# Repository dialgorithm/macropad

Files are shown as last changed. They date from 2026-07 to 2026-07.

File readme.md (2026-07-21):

# macropad

xiao esp32s3 based 10 key custom wireless macropad with a display to show the current layer and controls.

There are 10 keys, 1 layer switch button, 1 rotary encoder, and a slide switch for turning on and off.

## Schematics + PCB

Designed using KiCad.

| Schematic | PCB Layout | 3D PCB |
| --- | --- | --- |
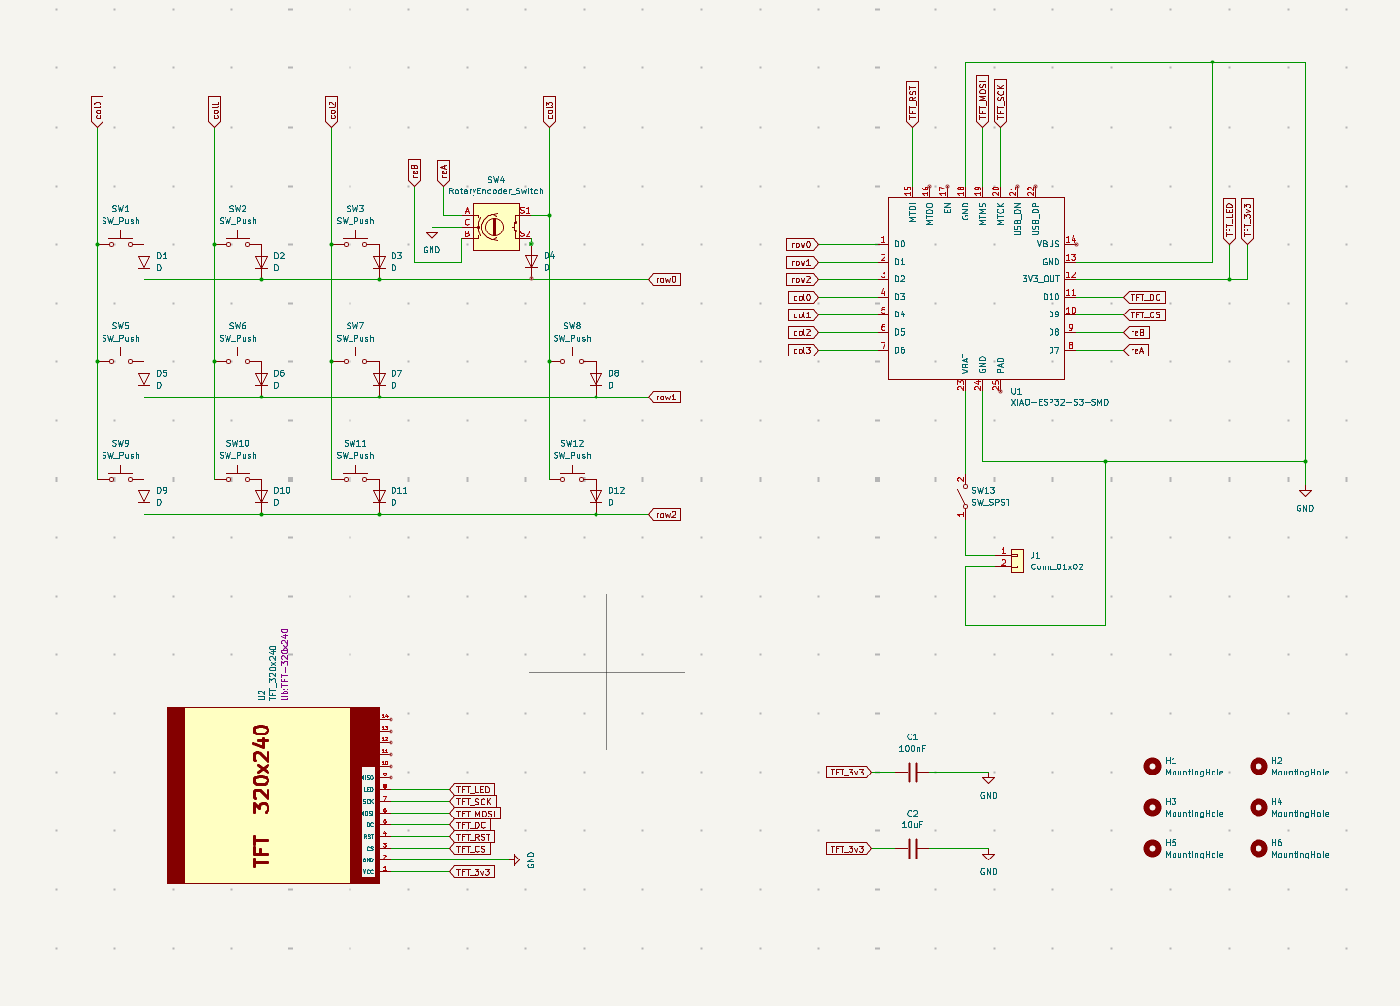
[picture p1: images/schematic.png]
schematic
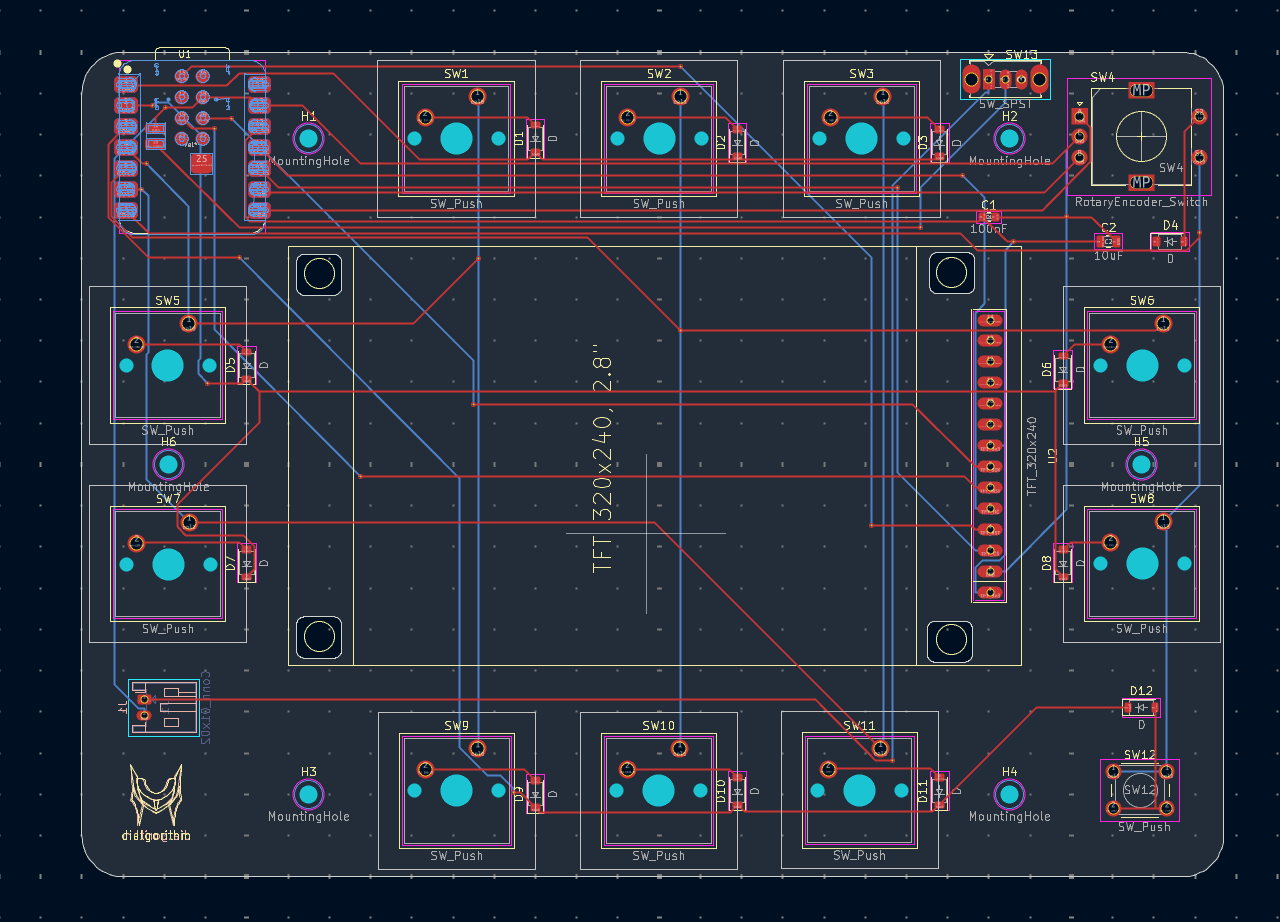
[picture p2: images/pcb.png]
pcb
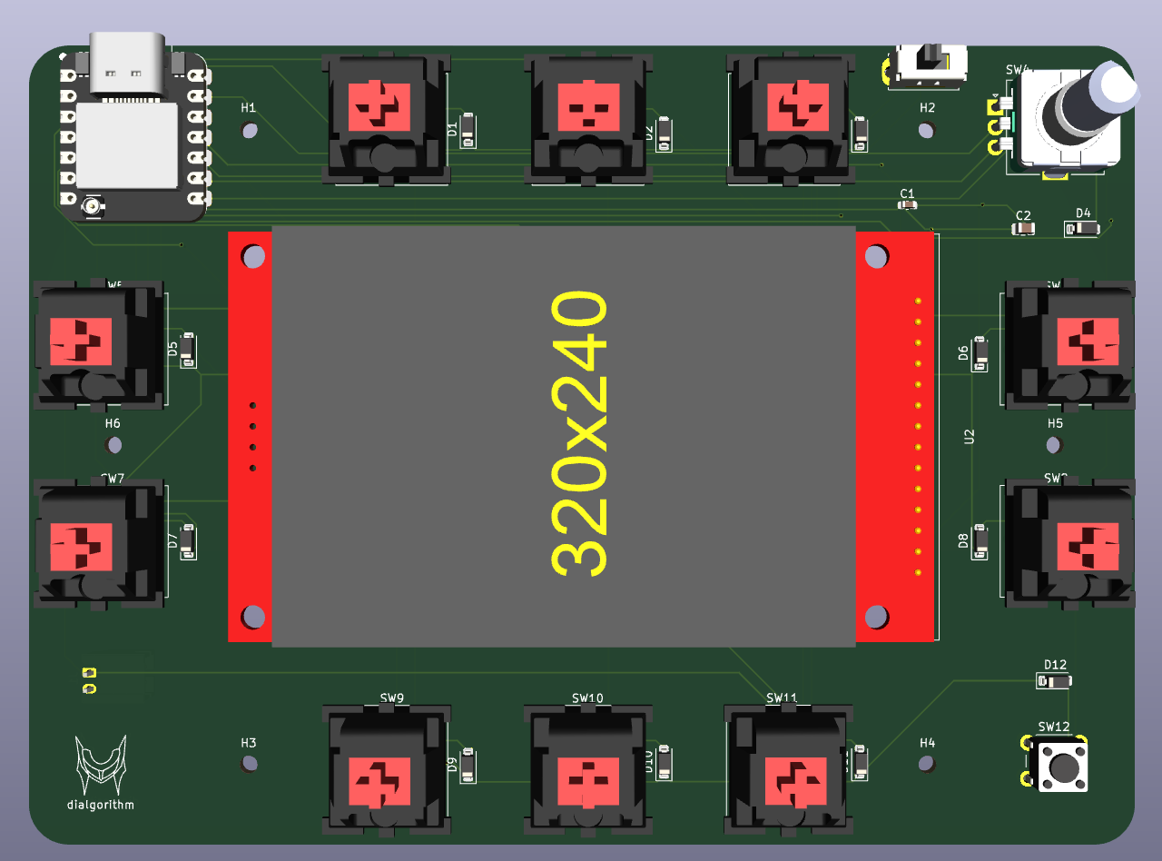
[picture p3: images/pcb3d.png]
pcb3d
|  |  |  |

## CAD

I am using cnc'd acrylic transparent sheets to keep a minimal and clean look.

| Top View | Side View | Bottom View |
| --- | --- | --- |
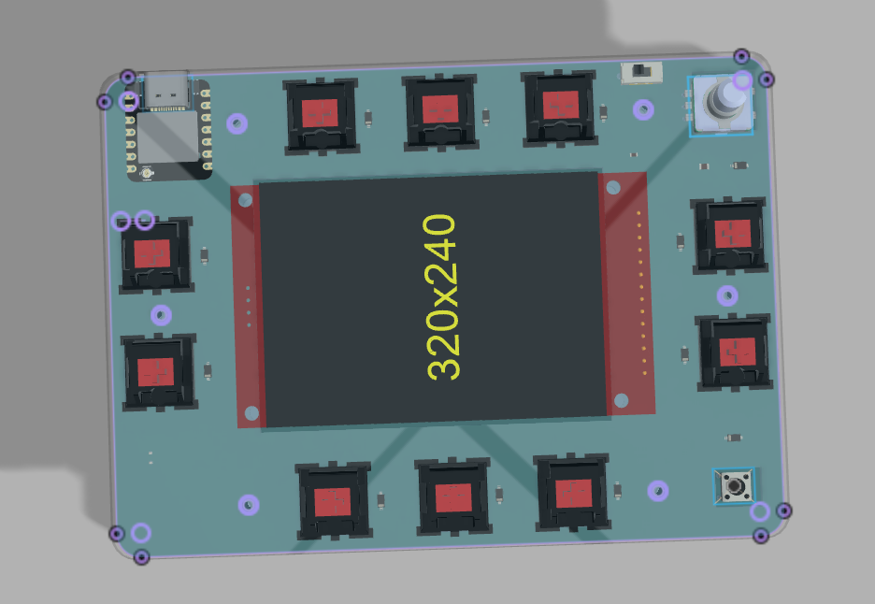
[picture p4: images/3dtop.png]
3dtop
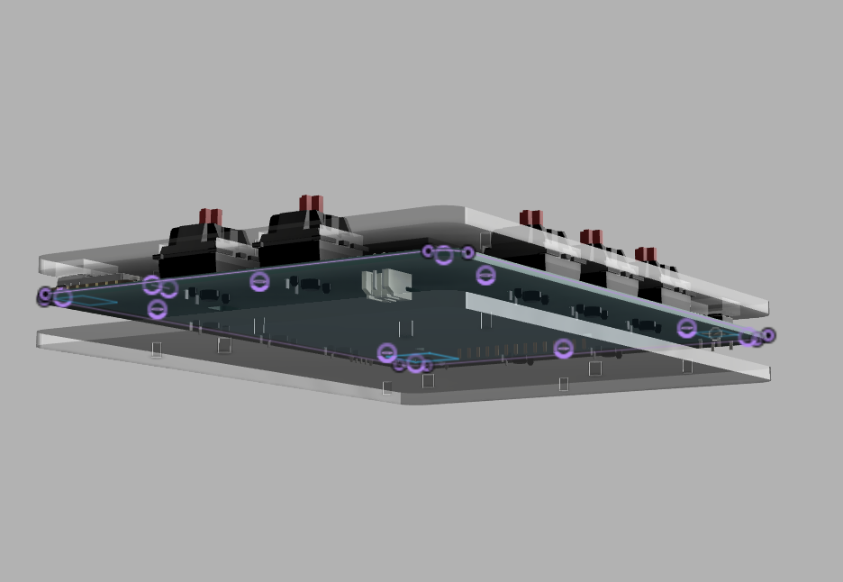
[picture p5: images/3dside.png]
3dside
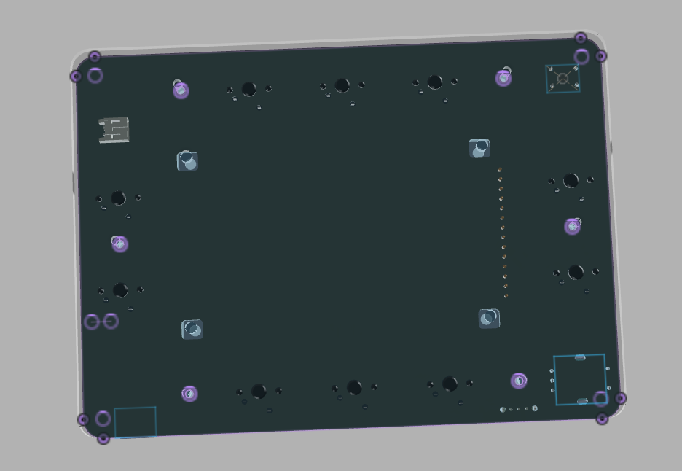
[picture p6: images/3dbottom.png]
3dbottom
|  |  |  |

## BOM

you can find the detailed bill of materials [here](bom.csv)

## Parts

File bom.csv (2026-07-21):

Item | Quantity | Cost | Source
Bottom Plate CNC | 1 | $3 | https://robu.in/product/online-laser-cutting-service/
Switch Plate CNC | 1 | $3 | https://robu.in/product/online-laser-cutting-service/
PCB | 1 | $28.5 | https://robu.in/product/online-pcb-manufacturing-service/ (JLCPCB costs $20 and with customs it would cost me $40)
XIAO ESP32-S3 | 1 | $9.5 | https://robocraze.com/products/seeed-studio-xiao-esp32-s3-development-board-supports-wi-fi-bluetooth-5-0
Switches | 10 | $5 | https://stackskb.com/store/hmx-xinhai-pack-of-10/
Push Button | 1 | $2 | https://www.amazon.in/Square-tactile-button-switch-White/dp/B0FJGXRXHX?th=1
Rotary Encoder | 1 | $1 | https://robu.in/product/hongyan-ec11h-7ce15p1zd15f7-rotary-encoder-with-push-button-switch-vertical-plug-in-5-pin-360-degree/
Encoder Knob | 1 | $0.3 | https://robu.in/product/potentiometer-knob-rotary-switch-cap-black-color-pack-of-5-pcs/
100nF 0603 Capacitor | 1 | $1.2 | https://www.amazon.in/0-1uF-100nF-Capacitor-0603-pack/dp/B0DK95ZBFM
10uF 0805 Capacitor | 1 | $3.2 | https://www.amazon.in/RajRetaiil-10uF-10000nF-Capacitor-Package/dp/B0GPW3R3TK
1N4148W Diode | 13 | $0.5 | https://robu.in/product/1n4148w-semtech-75v-independent-type-1v50ma-4ns-150ma-sod-123-switching-diodes-rohs/
Right Angle JST 2 pin | 1 | $1.2 | https://www.amazon.in/Right-Angle-Connector-2-5mm-Pitch/dp/B0CLY3CM63
Right Angle SPDT Switch | 1 | $1.2 | https://www.amazon.in/Mini-Slide-Switch-Right-Angle/dp/B0B434R6QF
Keycaps | 10 | $6.5 | https://www.amazon.in/CALANDISTM-Replacement-Switches-Keyboards-Pointers/dp/B0F14119N8?s=electronics
240x320 TFT Display | 1 | $7 | https://robu.in/product/2-4-inch-spi-interface-240x320-touch-screen-tft-display-module/
M2 6mm standoff | 6 | $2.3 | https://stackskb.com/store/m2-spacer-standoff-6mm-brass-nickel/
M2 5mm standoff | 6 | $2.3 | https://stackskb.com/store/m2-spacer-standoff-5mm-brass-nickel/
M2 10mm screws | 6 | $4 | https://www.amazon.in/BMOSESE%C2%AE-10MM-Length-Phillips-Screws/dp/B0FHHTPXD1
M2 8mm screws | 6 | $0.5 | https://stackskb.com/store/m2-screw-8mm-stainless-steel/
Rubber Feet | 6 | $4 | https://www.amazon.in/Pro3D-Vibration-Rubber-Damper-Balls/dp/B0CV9MFVJQ
Battery | 1 | $4 | https://www.amazon.in/KP-Original-902232-Rechargeable-Battery-Connector/dp/B0CY8GGW1B
Total | - | ~$95 | -

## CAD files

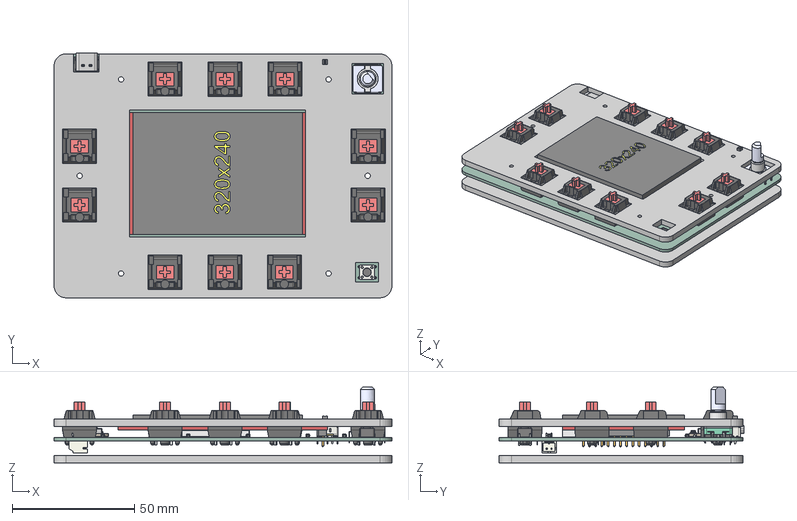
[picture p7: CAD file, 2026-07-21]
CAD/assembly.step
138.5 x 100.3 x 31.1 mm
D_SOD-123_1 x 12
C_0805_2012Metric_1
C_0603_1608Metric_1
SW_Slide_SPDT_Straight_CK_OS102011MS2Q_1
BOSS-EXTRUDE14_8_
BOSS-EXTRUDE7_4_
BOSS-EXTRUDE7_3_
BOSS-EXTRUDE14_4_
BOSS-EXTRUDE14_2_
BOSS-EXTRUDE14_11_
BOSS-EXTRUDE7_7_
BOSS-EXTRUDE14_9_
BOSS-EXTRUDE14_3_
BOSS-EXTRUDE14_7_
MIRROR2
BOSS-EXTRUDE14_5_
BOSS-EXTRUDE14_12_
BOSS-EXTRUDE7_8_
BOSS-EXTRUDE7_1_
BOSS-EXTRUDE14_10_
BOSS-EXTRUDE7_9_
BOSS-EXTRUDE14_6_
BOSS-EXTRUDE14_1_
BOSS-EXTRUDE7_6_
BOSS-EXTRUDE7_2_
CUT-EXTRUDE5
BOSS-EXTRUDE7_5_
Shield
Pins x 2
U.FL-R-SMT-1_10_ v1
EC11-Base
EC11-Shaft-F
EC11-Housing-THT
SW_PUSH_6mm_1
Body-header
Body-pins
Body-display
Body-sdcard
Body-board
JST_S2B_PH_K
macropad_PCB
bottomplate
switchplate

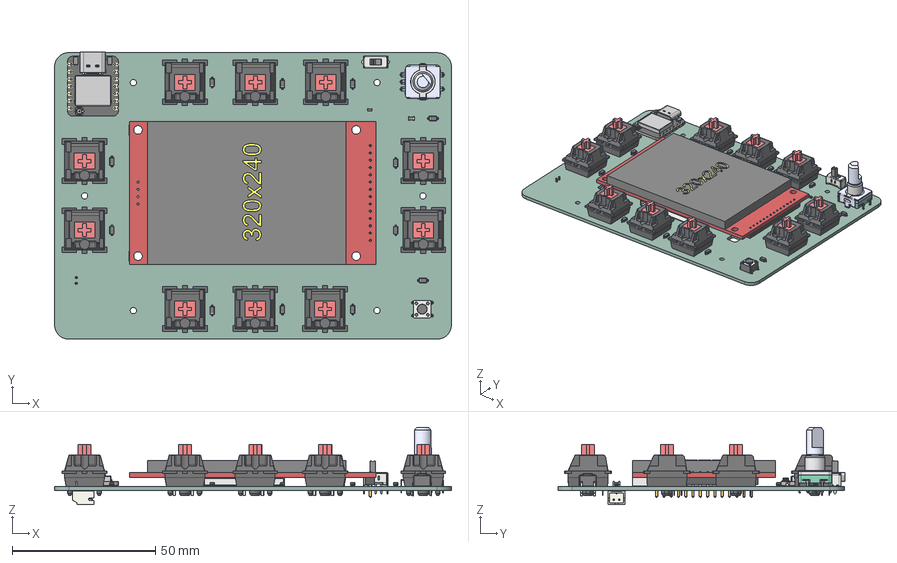
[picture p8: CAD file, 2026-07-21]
KiCad/macropad.step
138.5 x 100.3 x 27.0 mm
D_SOD-123 x 12
C_0805_2012Metric
C_0603_1608Metric
SW_Slide_SPDT_Straight_CK_OS102011MS2Q
BOSS-EXTRUDE14_8_
BOSS-EXTRUDE7_4_
BOSS-EXTRUDE7_3_
BOSS-EXTRUDE14_4_
BOSS-EXTRUDE14_2_
BOSS-EXTRUDE14_11_
BOSS-EXTRUDE7_7_
BOSS-EXTRUDE14_9_
BOSS-EXTRUDE14_3_
BOSS-EXTRUDE14_7_
MIRROR2
BOSS-EXTRUDE14_5_
BOSS-EXTRUDE14_12_
BOSS-EXTRUDE7_8_
BOSS-EXTRUDE7_1_
BOSS-EXTRUDE14_10_
BOSS-EXTRUDE7_9_
BOSS-EXTRUDE14_6_
BOSS-EXTRUDE14_1_
BOSS-EXTRUDE7_6_
BOSS-EXTRUDE7_2_
CUT-EXTRUDE5
BOSS-EXTRUDE7_5_
Shield
Pins x 2
U.FL-R-SMT-1_10_ v1
EC11-Base
EC11-Shaft-F
EC11-Housing-THT
SW_PUSH_6mm
Body-header
Body-pins
Body-display
Body-sdcard
Body-board
JST_S2B_PH_K
macropad_PCB

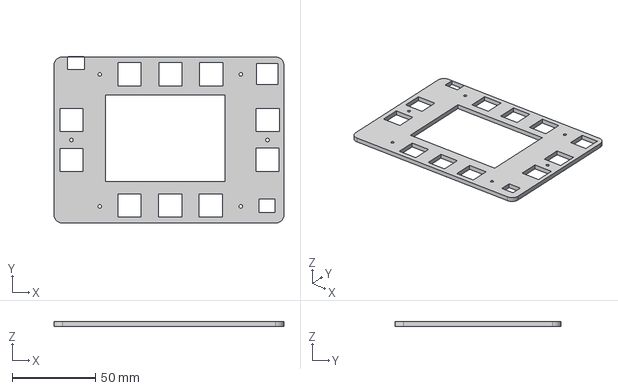
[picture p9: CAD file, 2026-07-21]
CAD/switchplate.step
138.5 x 100.0 x 3.00 mm

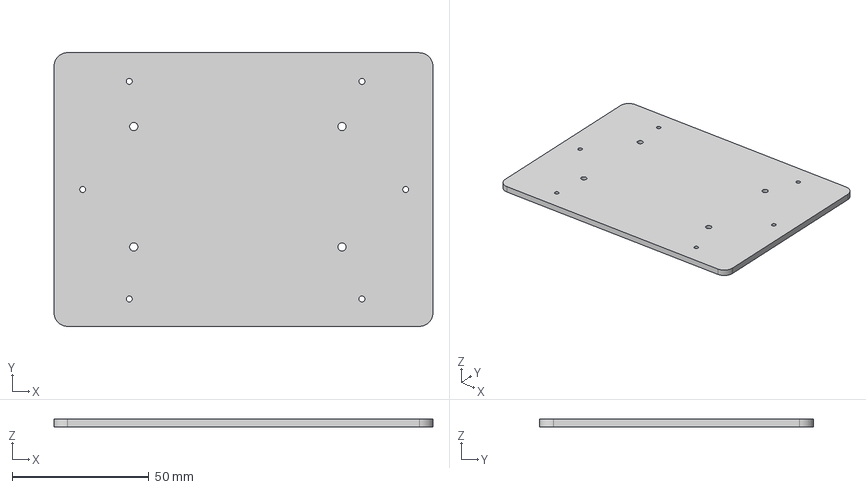
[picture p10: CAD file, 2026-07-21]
CAD/bottomplate.step
138.5 x 100.0 x 3.00 mm

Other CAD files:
KiCad/.step
CAD/bottomplate.dxf
CAD/switchplate.dxf

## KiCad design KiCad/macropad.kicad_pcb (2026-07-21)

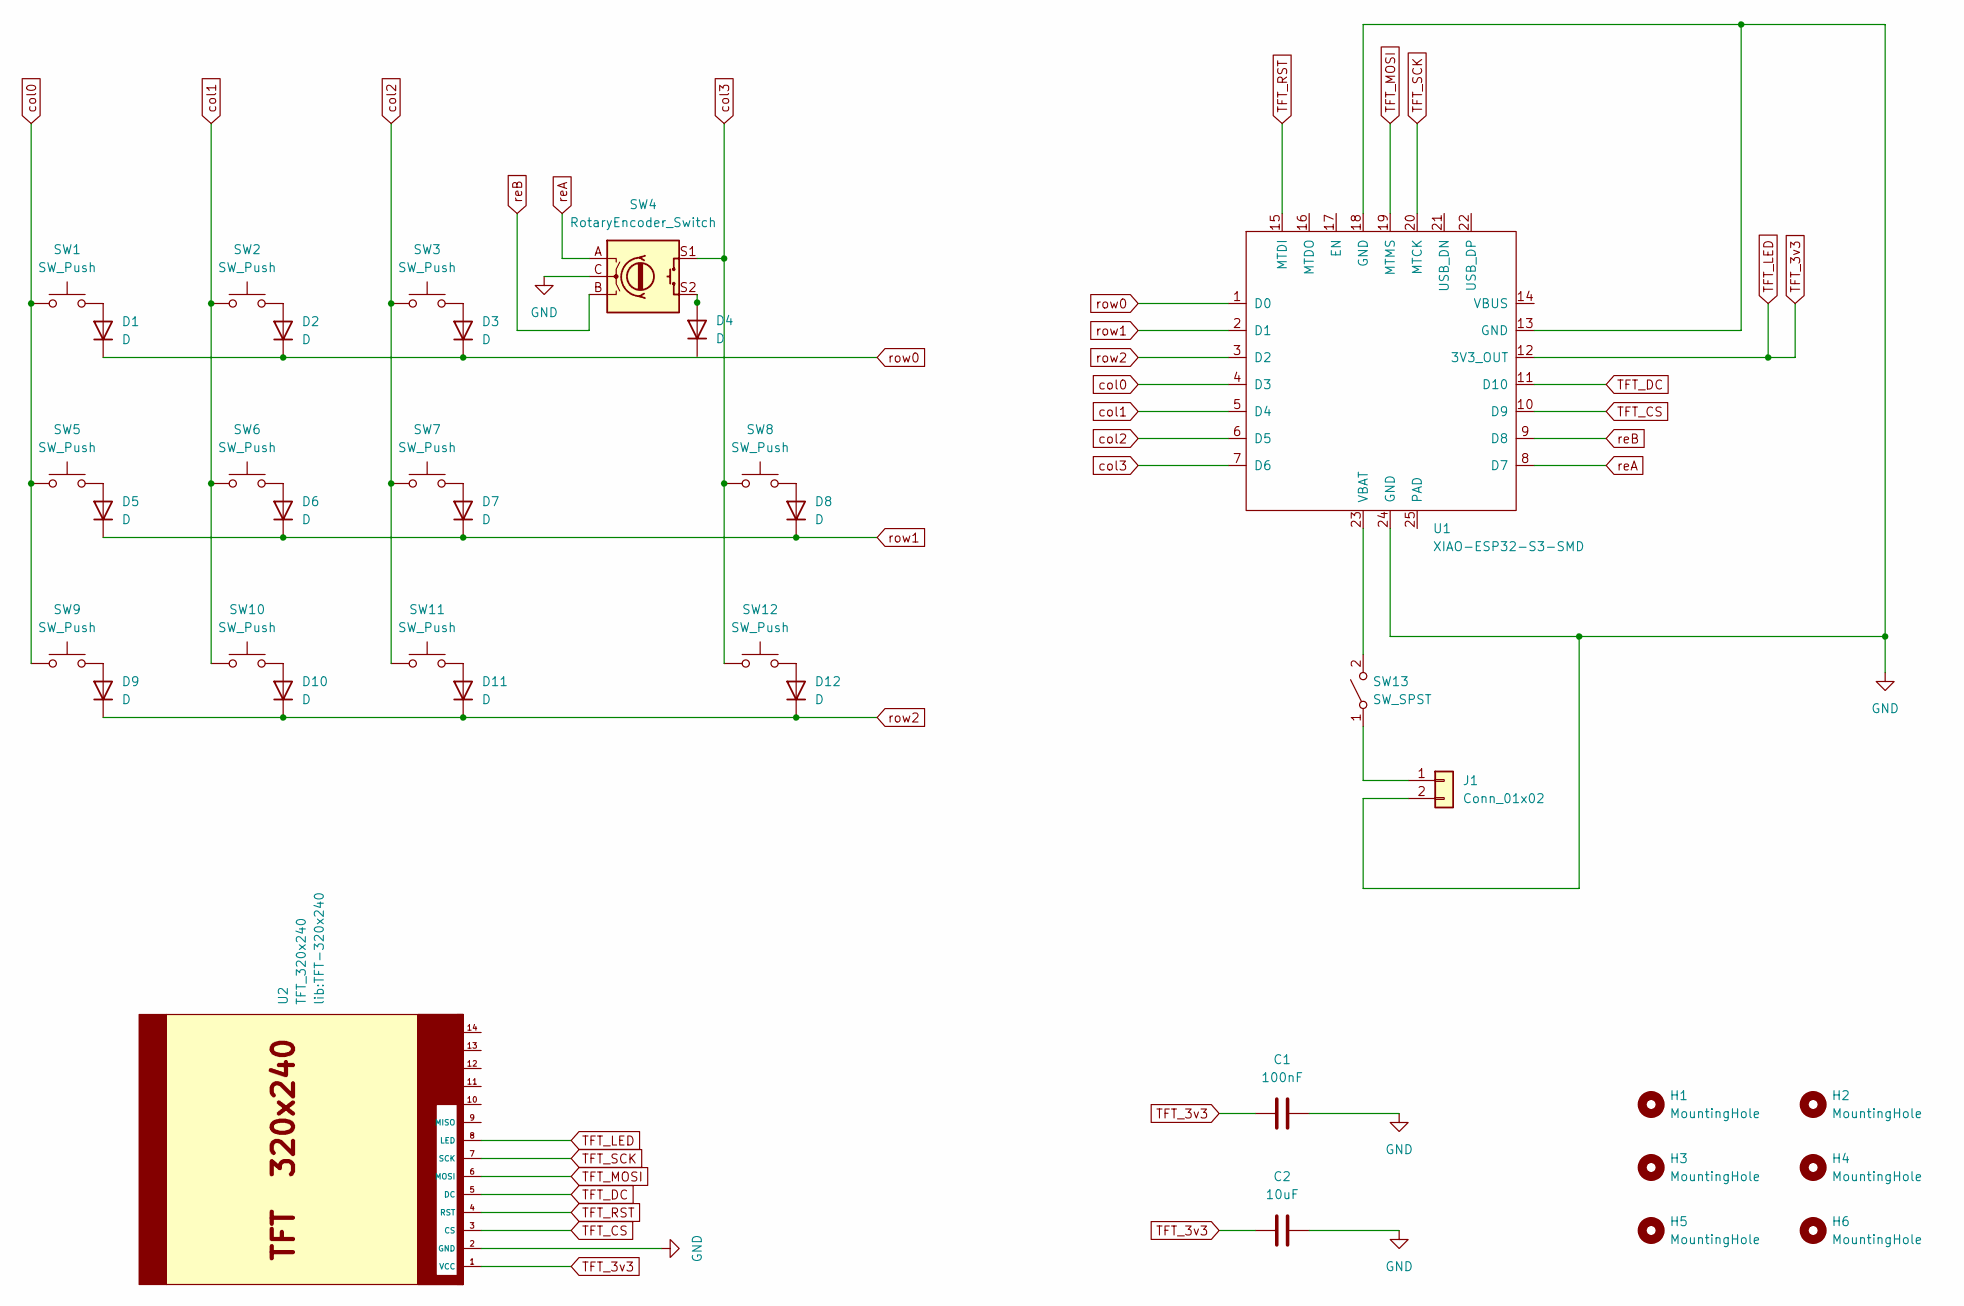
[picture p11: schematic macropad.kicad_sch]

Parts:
C1: 100nF; C_0603_1608Metric
C2: 10uF; C_0805_2012Metric
D1, D2, D3, D4, D5, D6, D7, D8, D9, D10, D11, D12: D; D_SOD-123
H1, H2, H3, H4, H5, H6: MountingHole; MountingHole_2.2mm_M2_ISO7380
J1: Conn_01x02; JST_PH_S2B-PH-K_1x02_P2.00mm_Horizontal
SW1, SW2, SW3, SW5, SW6, SW7, SW8, SW9, SW10, SW11: SW_Push; SW_Cherry_MX_1.00u_PCB
SW4: RotaryEncoder_Switch; RotaryEncoder_Alps_EC11E-Switch_Vertical_H20mm
SW12: SW_Push; SW_PUSH_6mm
SW13: SW_SPST; SW_Slide_SPDT_Straight_CK_OS102011MS2Q
U1: XIAO-ESP32-S3-SMD
U2: TFT_320x240; TFT-320x240

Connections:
GND: C1.2, C2.2, J1.2, SW4.C, U1.13 (GND), U1.18 (GND), U1.24 (GND), U2.2 (GND)
unnamed: D1.2 (A), SW1.2
unnamed: D2.2 (A), SW2.2
unnamed: D3.2 (A), SW3.2
unnamed: D4.2 (A_2), SW4.S2
unnamed: D5.2 (A), SW5.2
unnamed: D6.2 (A), SW6.2
unnamed: D7.2 (A), SW7.2
unnamed: D8.2 (A), SW8.2
unnamed: D9.2 (A), SW9.2
unnamed: D10.2 (A), SW10.2
unnamed: D11.2 (A), SW11.2
unnamed: D12.2 (A), SW12.2
unnamed: J1.1, SW13.1 (A)
unnamed: SW13.2 (B), U1.23 (VBAT)
TFT_3v3: C1.1, C2.1, U1.12 (3V3_OUT), U2.1 (VCC), U2.8 (LED)
TFT_CS: U1.10 (D9), U2.3 (CS)
TFT_DC: U1.11 (D10), U2.5 (DC)
TFT_MOSI: U1.19 (MTMS), U2.6 (MOSI)
TFT_RST: U1.15 (MTDI), U2.4 (RST)
TFT_SCK: U1.20 (MTCK), U2.7 (SCK)
col0: SW1.1, SW5.1, SW9.1, U1.4 (D3)
col1: SW2.1, SW6.1, SW10.1, U1.5 (D4)
col2: SW3.1, SW7.1, SW11.1, U1.6 (D5)
col3: SW4.S1, SW8.1, SW12.1, U1.7 (D6)
reA: SW4.A, U1.8 (D7)
reB: SW4.B, U1.9 (D8)
row0: D1.1 (K), D2.1 (K), D3.1 (K), U1.1 (D0)
row1: D5.1 (K), D6.1 (K), D7.1 (K), D8.1 (K), U1.2 (D1)
row2: D9.1 (K), D10.1 (K), D11.1 (K), D12.1 (K), U1.3 (D2)

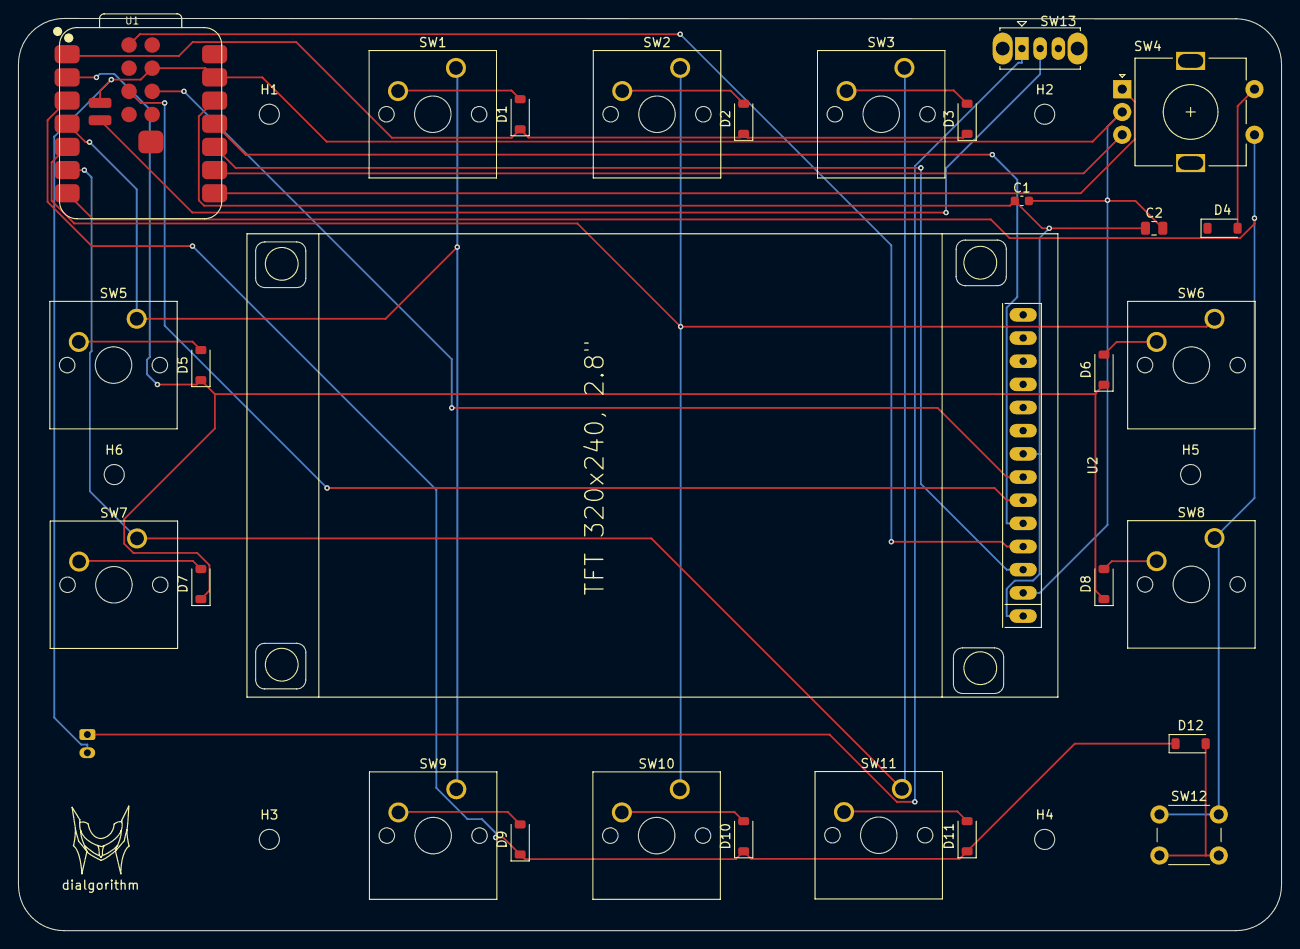
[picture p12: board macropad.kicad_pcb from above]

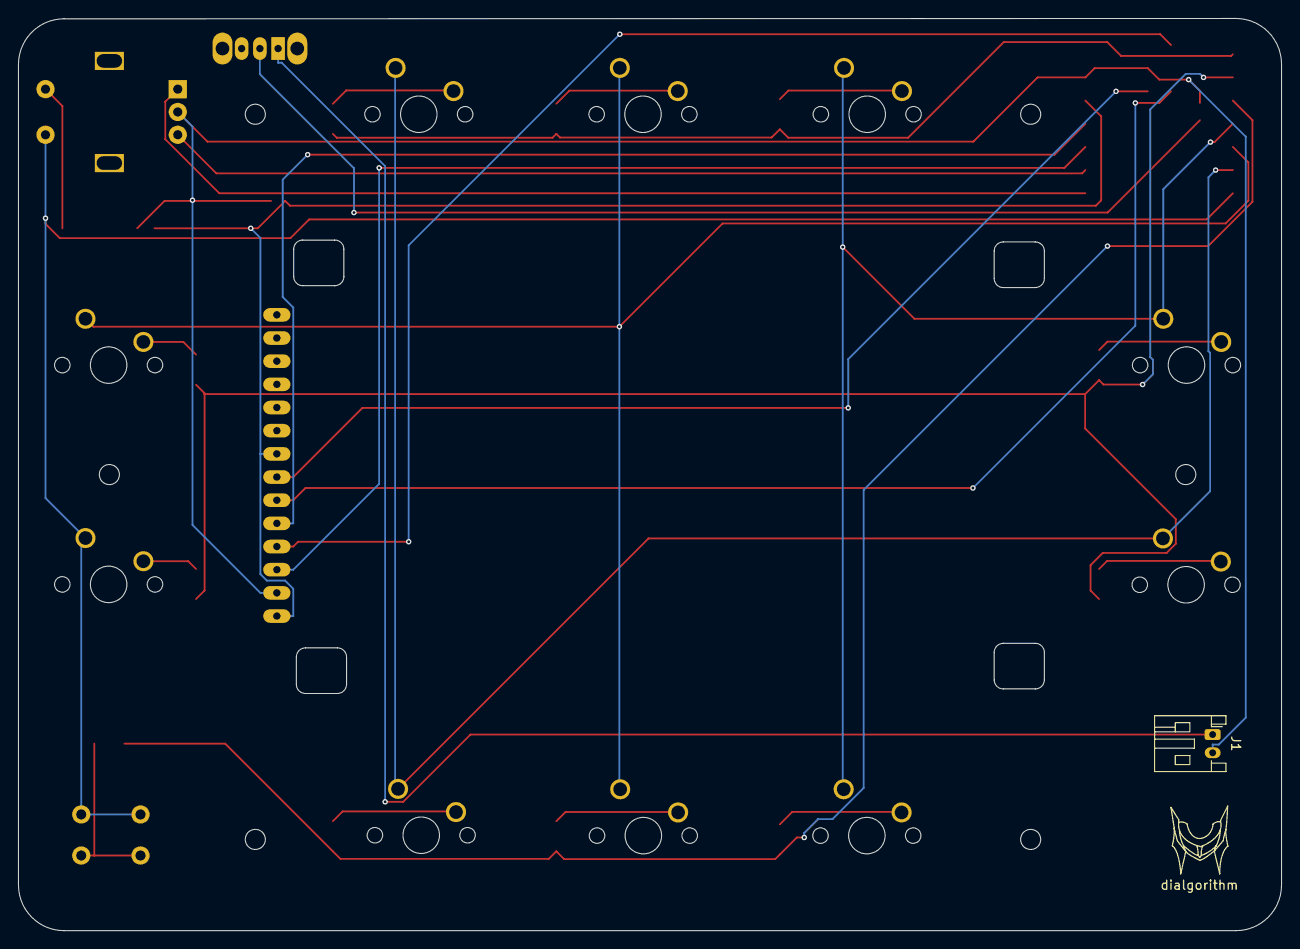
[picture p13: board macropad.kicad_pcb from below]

Board: 2 copper layers, 138.5 x 100.0 mm, 38 parts (2 on the bottom side), 30 nets.

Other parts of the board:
dialgorithm: dialgorithm
dialgorithm#2: dialgorithm
